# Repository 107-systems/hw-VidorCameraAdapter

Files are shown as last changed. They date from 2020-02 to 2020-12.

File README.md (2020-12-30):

VidorCameraAdapter
==================

<p align="center">
  
</p>

Adapter to connect a OV2640 camera module to the Mini PCIe connector of the Arduino MKR Vidor 4000.

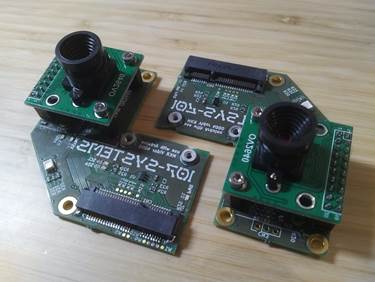
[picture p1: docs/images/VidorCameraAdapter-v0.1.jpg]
VidorCameraAdapter v0.1


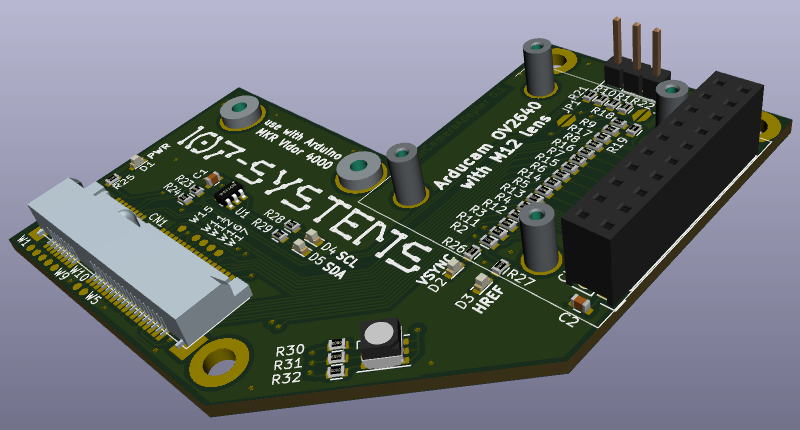
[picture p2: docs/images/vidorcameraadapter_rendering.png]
vidorcameraadapter rendering


## Pinout

This adapter uses only the pins of the Mini PCIe connector of the Arduino MKR Vidor (CN1).

| Pin Number  | Pin Name | Signal | Description |
|:---:|:---:|:---:| --- |
|  1 | WM.WM_PIO2 PEX_PIN1  | n.c. | Connected to the WIFI NINA module on Vidor |
|  3 | WM.WM_PIO3 PEX_PIN3  | n.c. | Connected to the WIFI NINA module on Vidor |
|  5 | WM.WM_PIO4 PEX_PIN5  | n.c. | Connected to the WIFI NINA module on Vidor |
|  6 | PEX_PIN6 | LED_G  | RGB status LED (green) |
|  7 | WM.WM_PIO34 PEX_PIN7 | n.c. | Connected to the WIFI NINA module on Vidor |
|  8 | PEX_PIN8 | LED_R  | RGB status LED (red) |
| 10 | PEX_PIN10 | SDA_V  | I2C to configure OV2640 module |
| 11 | PEX_PIN11 | n.c. | Reserved for future use |
| 12 | PEX_PIN12 | SCL_V  | I2C to configure OV2640 module |
| 13 | PEX_PIN13 | DOUT6  | Data from OV2640 module |
| 14 | PEX_PIN14 | RST | reset for OV2640 module |
| 16 | PEX_PIN16 | PWDN | Power down for OV2640 module |
| 17 | WM.WM_PIO24 | n.c. | Connected to the WIFI NINA module on Vidor |
| 19 | WM.WM_PIO25 | n.c. | Connected to the WIFI NINA module on Vidor |
| 20 | PEX_PIN20 | VSYNC  | Sync from OV2640 module |
| 22 | PEX_RST | n.c. | Pull up resistor on Vidor |
| 23 | PEX_PIN23 | PCLK | Pixel clock from OV2640 module |
| 25 | PEX_PIN25 | DOUT4  | Data from OV2640 module |
| 28 | PEX_PIN28 | HREF | Sync from OV2640 module |
| 30 | PEX_PIN30 | n.c. | Pull up resistor on Vidor |
| 31 | PEX_PIN31 | DOUT5  | Data from OV2640 module |
| 32 | PEX_PIN32 | n.c. | Pull up resistor on Vidor |
| 33 | PEX_PIN33 | DOUT7  | Data from OV2640 module |
| 42 | PEX_PIN42 | DOUT0  | Data from OV2640 module |
| 44 | PEX_PIN44 | DOUT1  | Data from OV2640 module |
| 45 | PEX_PIN45 | LED_B  | RGB status LED (blue) |
| 46 | PEX_PIN46 | DOUT2  | Data from OV2640 module |
| 47 | PEX_PIN47 | XCLK | Clock for OV2640 module |
| 48 | PEX_PIN48 | DOUT3  | Data from OV2640 module |
| 49 | PEX_PIN49 | DOUT8  | Data from OV2640 module |
| 51 | PEX_PIN51 | DOUT9  | Data from OV2640 module |

All GND pins are connected to the GND plane and all +3V3 pins are conntected to the +3V3-rail.

## PCB

### Top

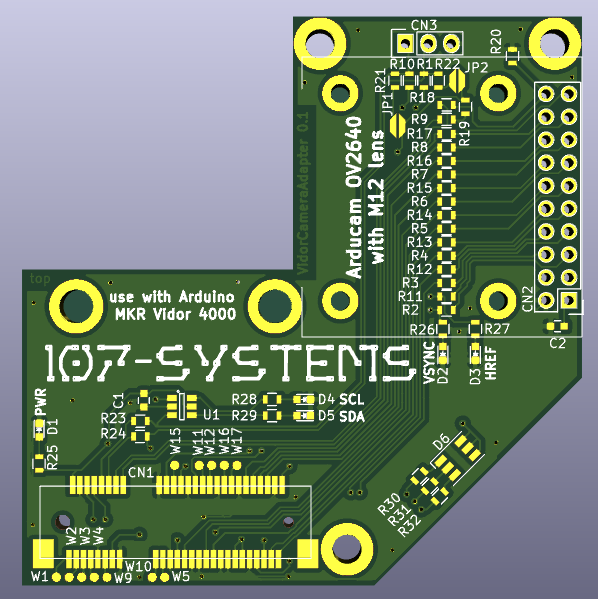
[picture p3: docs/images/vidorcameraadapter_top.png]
vidorcameraadapter PCB top


### Bot

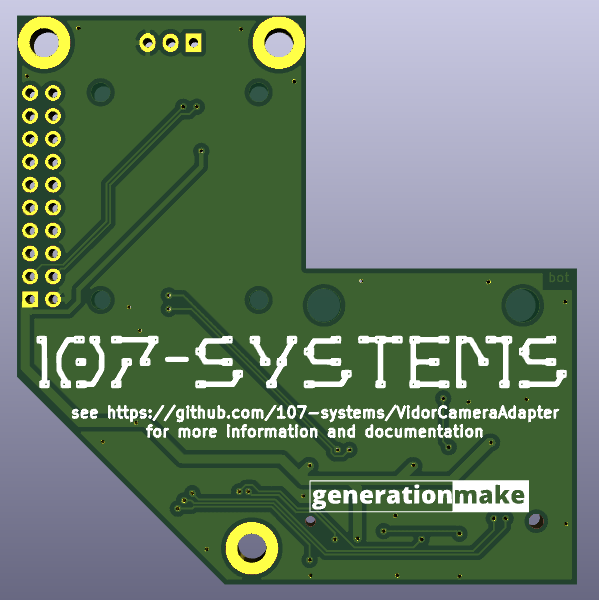
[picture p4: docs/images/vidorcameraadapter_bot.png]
vidorcameraadapter PCB bot


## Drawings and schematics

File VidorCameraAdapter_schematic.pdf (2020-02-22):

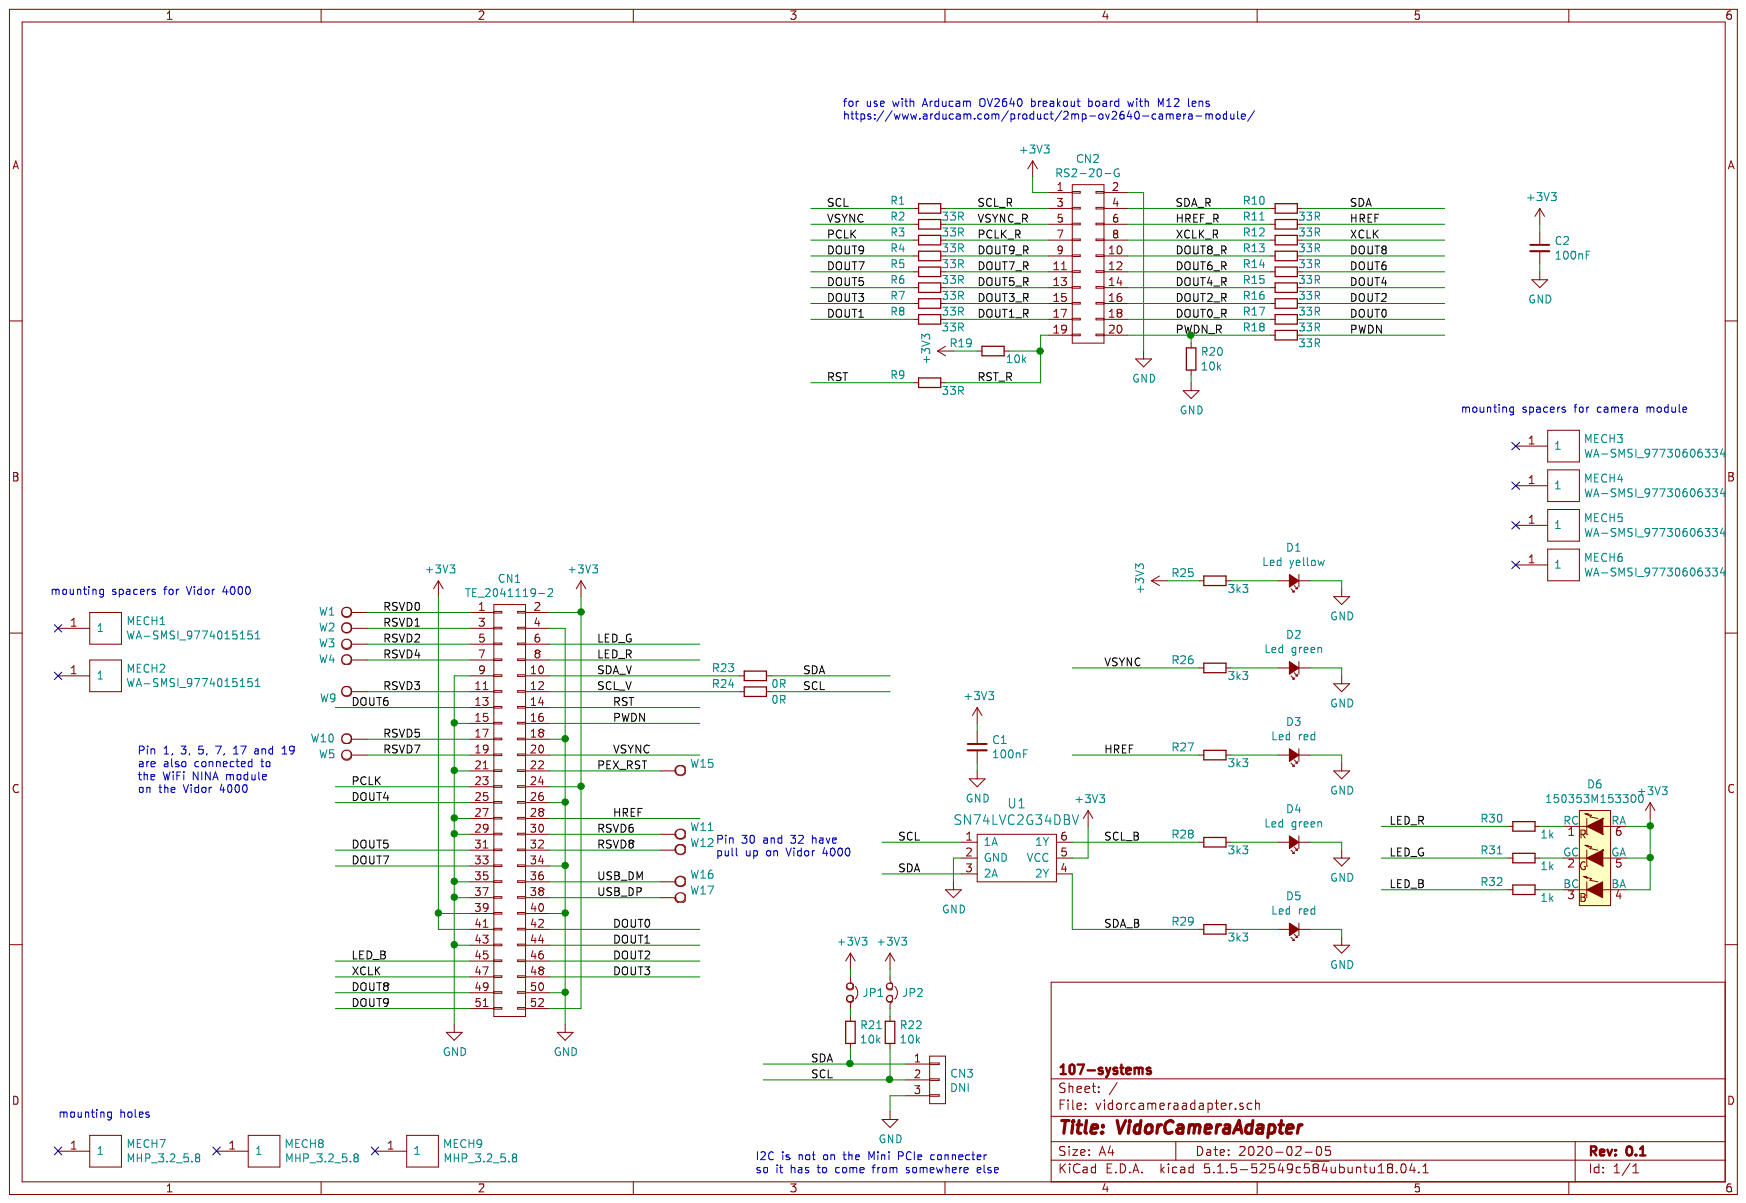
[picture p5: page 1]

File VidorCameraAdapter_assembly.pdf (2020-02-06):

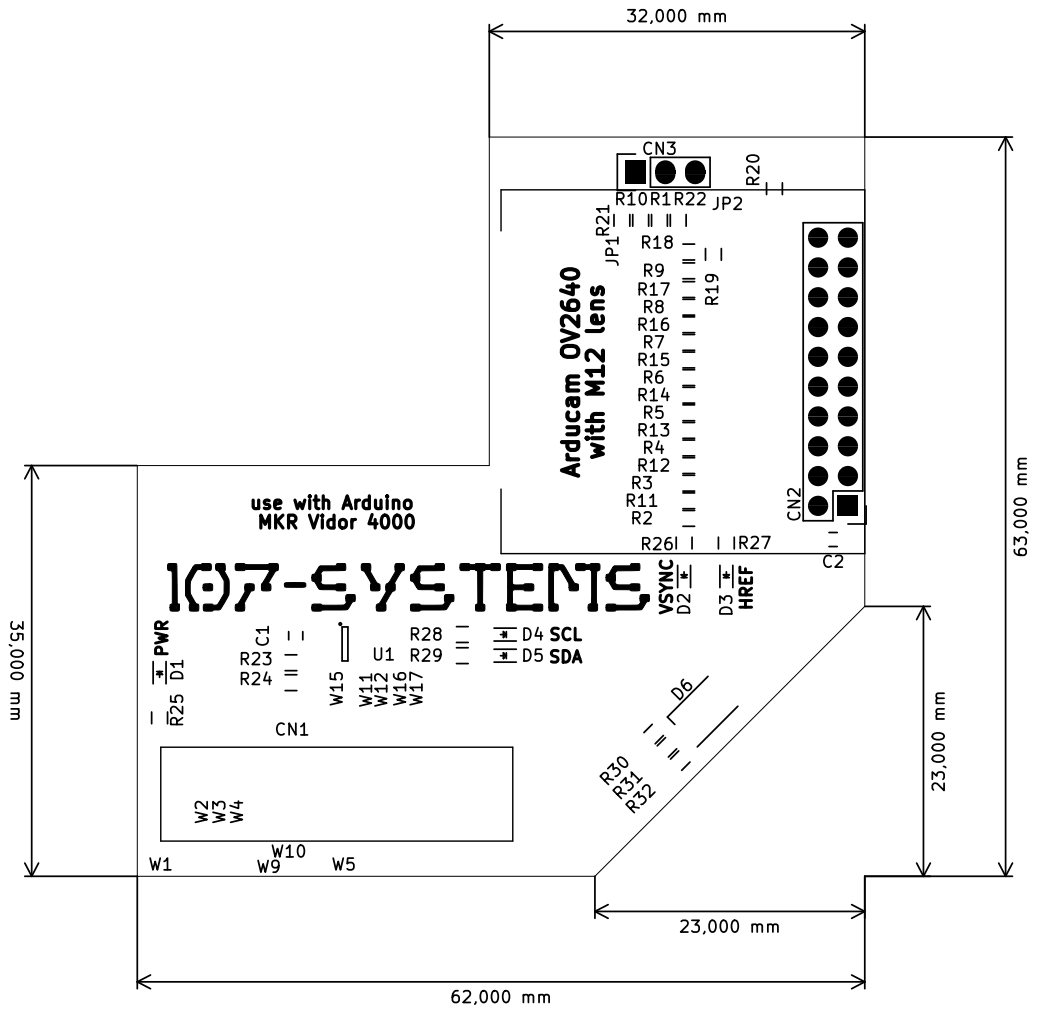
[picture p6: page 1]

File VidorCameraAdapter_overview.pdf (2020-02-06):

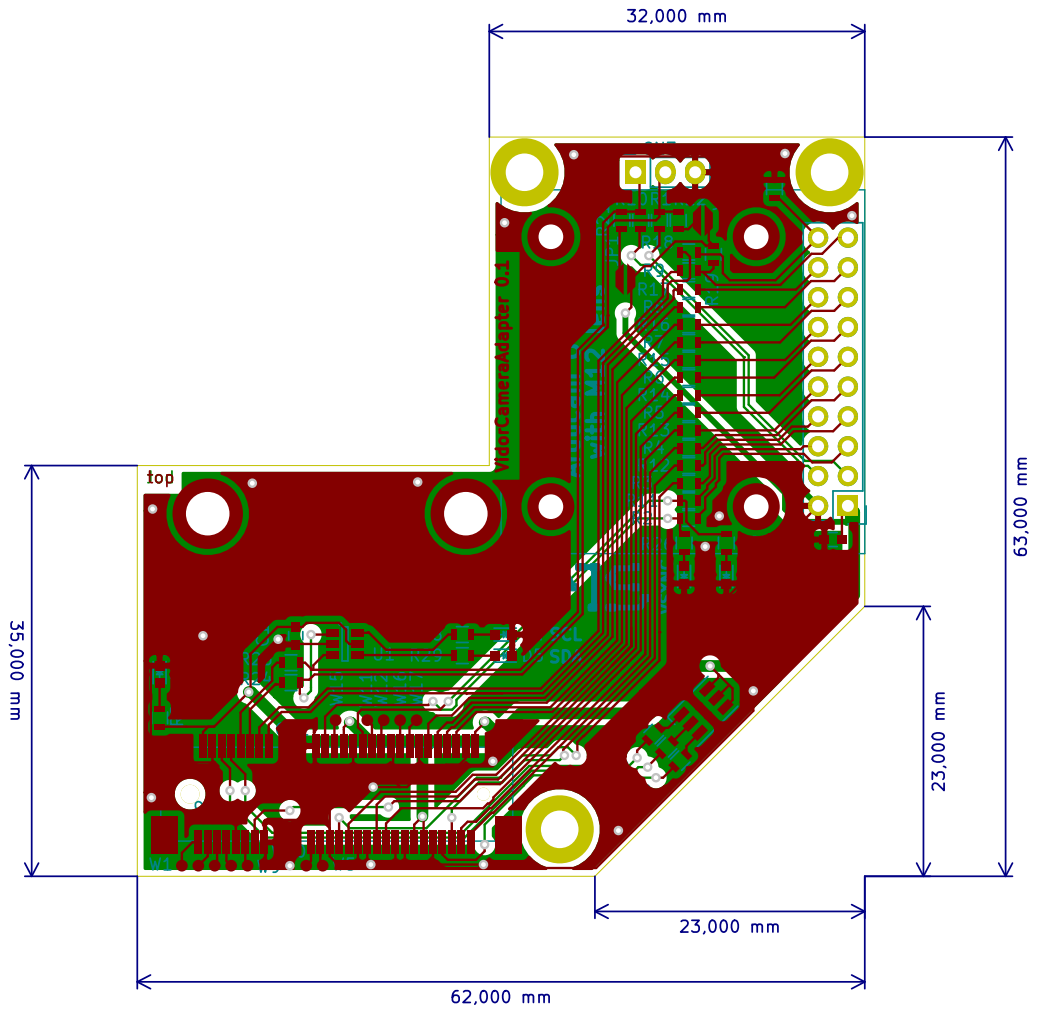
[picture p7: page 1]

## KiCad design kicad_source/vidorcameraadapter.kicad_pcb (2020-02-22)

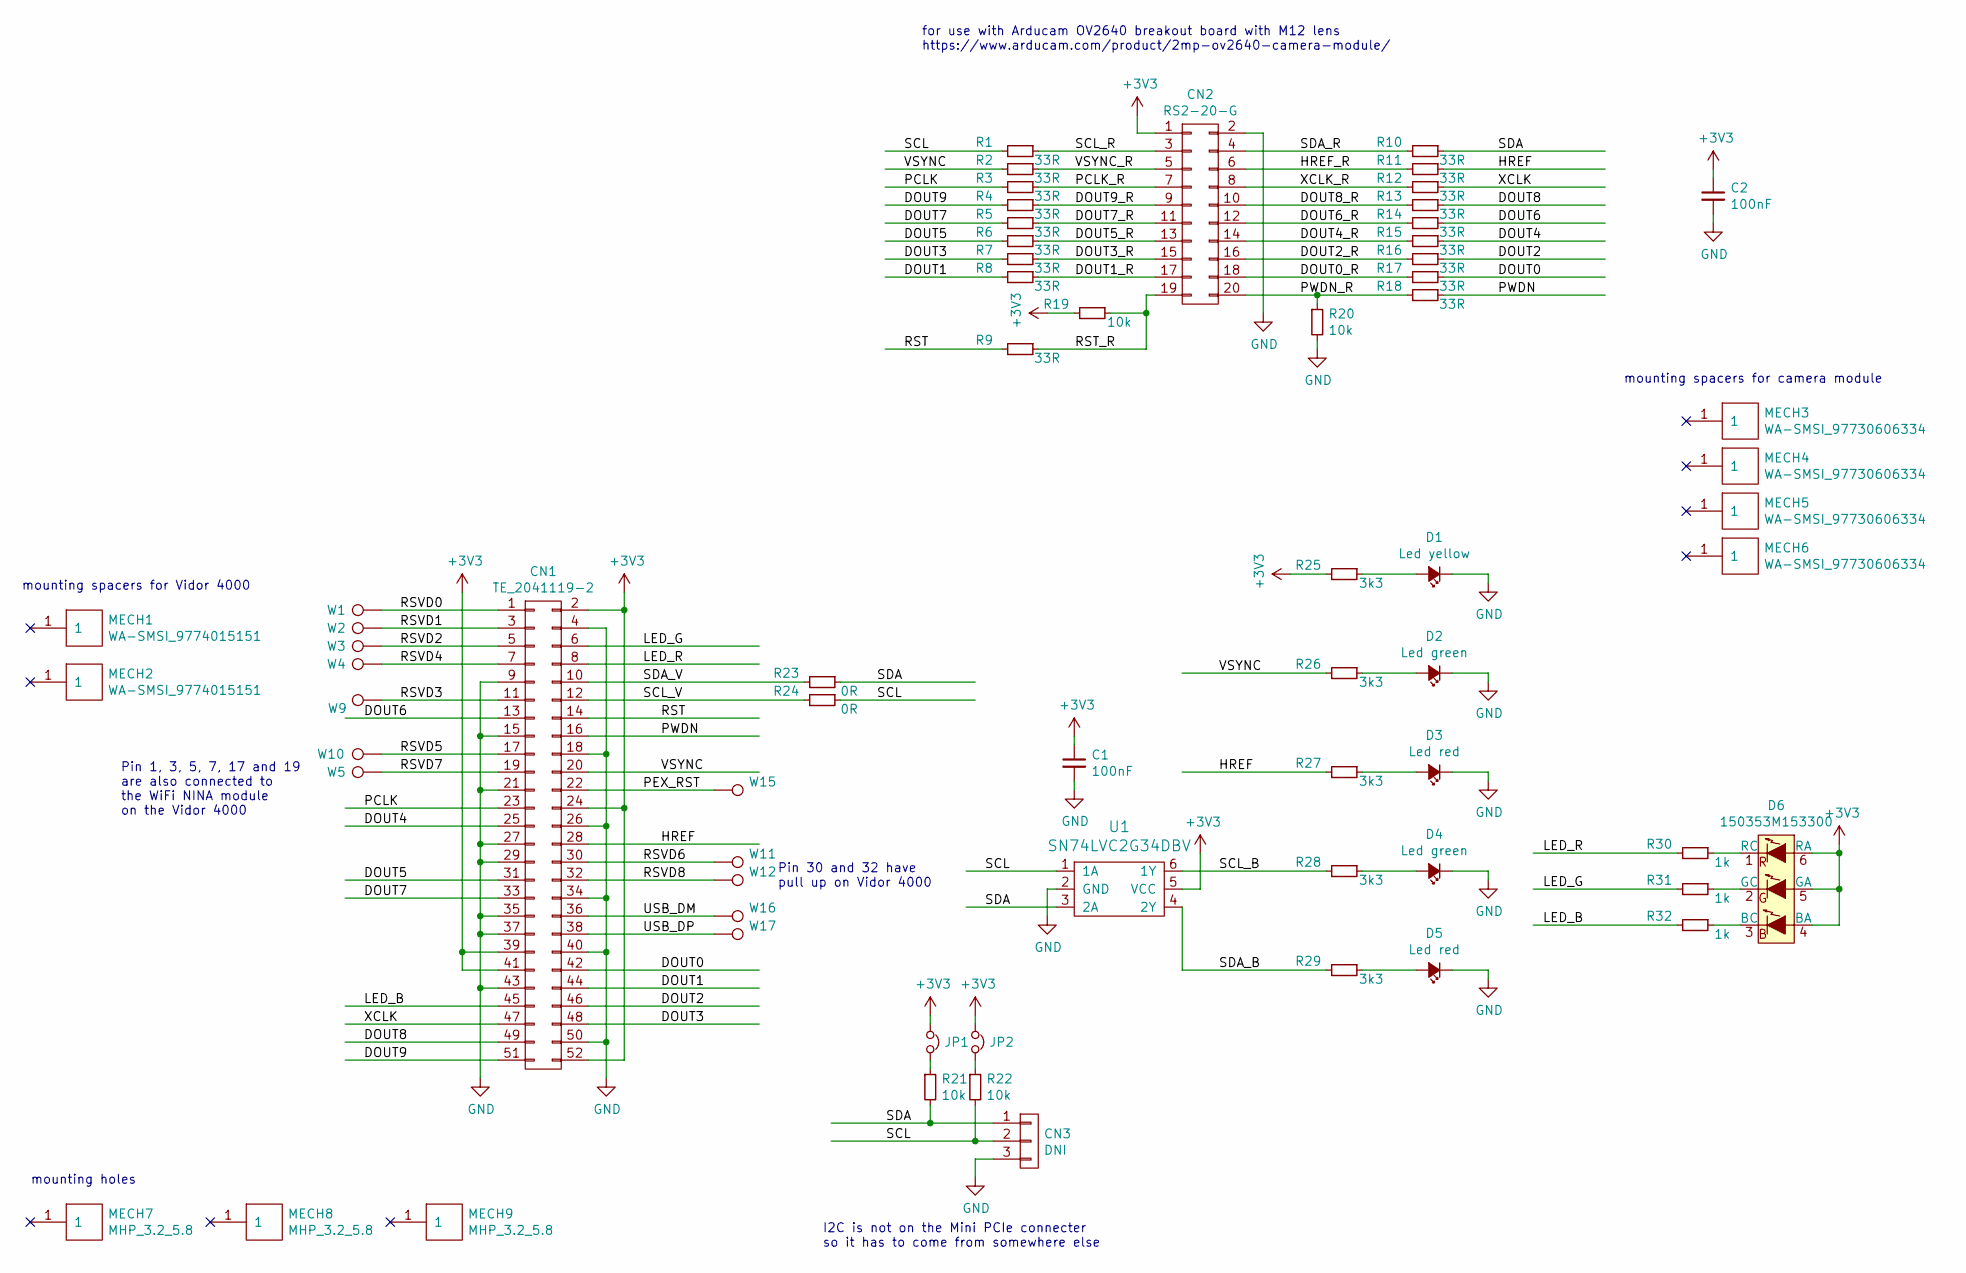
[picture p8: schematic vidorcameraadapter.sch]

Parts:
C1, C2: 100nF; C_0603
CN1: TE_2041119-2; MPCIe_4mm
CN2: RS2-20-G; WR-PHD_61302021821
CN3: DNI; Pin_Header_Straight_1x03
D1: Led yellow; LED_0603
D2, D4: Led green; LED_0603
D3, D5: Led red; LED_0603
D6: 150353M153300; LED_RGB_PLLC-6
JP1, JP2: Jumper_NC_Small; SolderJumper_2mm
MECH1, MECH2: WA-SMSI_9774015151
MECH3, MECH4, MECH5, MECH6: WA-SMSI_97730606334
MECH7, MECH8, MECH9: MHP_3.2_5.8
R1, R2, R3, R4, R5, R6, R7, R8, R9, R10, R11, R12, R13, R14, R15, R16, R17, R18: 33R; R_0603
R19, R20, R21, R22: 10k; R_0603
R23, R24: 0R; R_0603
R25, R26, R27, R28, R29: 3k3; R_0603
R30, R31, R32: 1k; R_0603
U1: SN74LVC2G34DBV; SOT-23-6
W1, W2, W3, W4, W5, W9, W10, W11, W12, W15, W16, W17: TEST_1P; SolderWirePad_single_1mmSMD

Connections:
+3V3: C1.1, C2.1, CN1.2, CN1.24, CN1.39, CN1.41, CN1.52, CN2.1, D6.4 (BA), D6.5 (GA), D6.6 (RA), JP1.1, JP2.1, R19.2, R25.2, U1.5 (VCC)
/DOUT0: CN1.42, R17.1
/DOUT0_R: CN2.18, R17.2
/DOUT1: CN1.44, R8.2
/DOUT1_R: CN2.17, R8.1
/DOUT2: CN1.46, R16.1
/DOUT2_R: CN2.16, R16.2
/DOUT3: CN1.48, R7.2
/DOUT3_R: CN2.15, R7.1
/DOUT4: CN1.25, R15.1
/DOUT4_R: CN2.14, R15.2
/DOUT5: CN1.31, R6.2
/DOUT5_R: CN2.13, R6.1
/DOUT6: CN1.13, R14.1
/DOUT6_R: CN2.12, R14.2
/DOUT7: CN1.33, R5.2
/DOUT7_R: CN2.11, R5.1
/DOUT8: CN1.49, R13.1
/DOUT8_R: CN2.10, R13.2
/DOUT9: CN1.51, R4.2
/DOUT9_R: CN2.9, R4.1
/HREF: CN1.28, R11.1, R27.2
/HREF_R: CN2.6, R11.2
/LED_B: CN1.45, R32.2
/LED_G: CN1.6, R31.2
/LED_R: CN1.8, R30.2
/PCLK: CN1.23, R3.2
/PCLK_R: CN2.7, R3.1
/PEX_RST: CN1.22, W15.1
/PWDN: CN1.16, R18.1
/PWDN_R: CN2.20, R18.2, R20.1
/RST: CN1.14, R9.2
/RST_R: CN2.19, R9.1, R19.1
/RSVD0: CN1.1, W1.1
/RSVD1: CN1.3, W2.1
/RSVD2: CN1.5, W3.1
/RSVD3: CN1.11, W9.1
/RSVD4: CN1.7, W4.1
/RSVD5: CN1.17, W10.1
/RSVD6: CN1.30, W11.1
/RSVD7: CN1.19, W5.1
/RSVD8: CN1.32, W12.1
/SCL: CN3.2, R1.2, R22.2, R24.1, U1.1 (1A)
/SCL_B: R28.2, U1.6 (1Y)
/SCL_R: CN2.3, R1.1
/SCL_V: CN1.12, R24.2
/SDA: CN3.1, R10.1, R21.2, R23.1, U1.3 (2A)
/SDA_B: R29.2, U1.4 (2Y)
/SDA_R: CN2.4, R10.2
/SDA_V: CN1.10, R23.2
/USB_DM: CN1.36, W16.1
/USB_DP: CN1.38, W17.1
/VSYNC: CN1.20, R2.2, R26.2
/VSYNC_R: CN2.5, R2.1
/XCLK: CN1.47, R12.1
/XCLK_R: CN2.8, R12.2
GND: C1.2, C2.2, CN1.4, CN1.9, CN1.15, CN1.18, CN1.21, CN1.26, CN1.27, CN1.29, CN1.34, CN1.35, CN1.37, CN1.40, CN1.43, CN1.50, CN2.2, CN3.3, D1.1 (K), D2.1 (K), D3.1 (K), D4.1 (K), D5.1 (K), R20.2, U1.2 (GND)
unnamed: D1.2 (A), R25.1
unnamed: D2.2 (A), R26.1
unnamed: D3.2 (A), R27.1
unnamed: D4.2 (A), R28.1
unnamed: D5.2 (A), R29.1
unnamed: D6.1 (RC), R30.1
unnamed: D6.2 (GC), R31.1
unnamed: D6.3 (BC), R32.1
unnamed: JP1.2, R21.1
unnamed: JP2.2, R22.1

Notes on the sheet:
Pin 30 and 32 have pull up on Vidor 4000
mounting spacers for Vidor 4000
mounting spacers for camera module
I2C is not on the Mini PCIe connecter so it has to come from somewhere else
for use with Arducam OV2640 breakout board with M12 lens https://www.arducam.com/product/2mp-ov2640-camera-module/
mounting holes
Pin 1, 3, 5, 7, 17 and 19 are also connected to the WiFi NINA module on the Vidor 4000

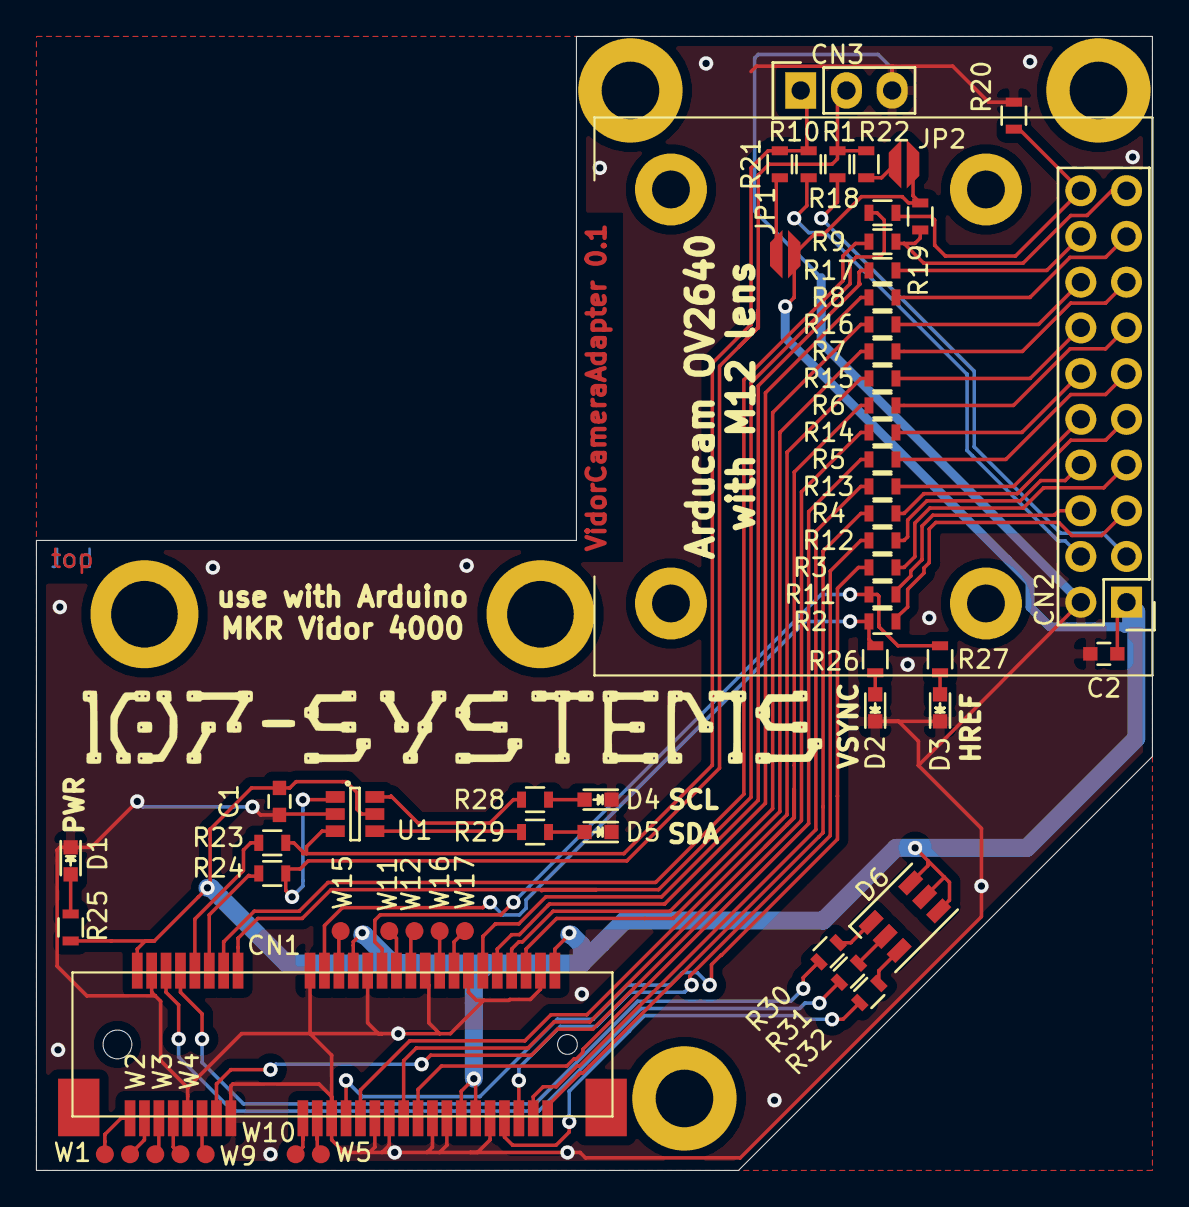
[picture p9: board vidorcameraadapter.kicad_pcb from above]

Board: 2 copper layers, 62.0 x 63.0 mm, 67 parts (0 on the bottom side), 67 nets.

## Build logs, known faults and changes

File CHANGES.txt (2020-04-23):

VidorCameraAdaptder - connect a OV2640 parallel camera to the Mini PCIe connector of the Arduino MKR Vidor 4000
see full documentation at https://github.com/107-systems/VidorCameraAdapter

changes

version 0.1 - 2020-02-05
* initial release

version 0.1.1 - 2020-02-22
* changed resistors for leds from 1k to 3k3

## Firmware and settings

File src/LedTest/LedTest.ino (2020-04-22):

// test program for all the LEDs on the VidorCameraAdapter
#include "VidorPeripherals.h"
const static int START_DELAY = 500;
const static int FPGA_LED_RED_PIN = 2;
const static int FPGA_LED_GREEN_PIN = 1;
const static int FPGA_LED_BLUE_PIN = 13;
const static int FPGA_I2C_SDA_PIN = 3;
const static int FPGA_I2C_SCL_PIN = 4;
const static int FPGA_VSYNC_PIN = 7;
const static int FPGA_HREF_PIN = 8;

void setup() {
  Serial.begin(115200);
  for(unsigned long const start = millis(); !Serial && (millis() - start) < 5000; ) {}  // wait for five seconds if Serial starts and then move on
  // Let's start by initializing the FPGA
  if (!FPGA.begin()) {
    Serial.println("Initialization failed!");
    while (1) {}
  }

  // Let's discover which version we are running
  int version = FPGA.version();
  Serial.print("Vidor bitstream version: ");
  Serial.println(version, HEX);
  pinMode(LED_BUILTIN, OUTPUT);

  // Let's also ask which IPs are included in this bitstream
  FPGA.printConfig();

  // Set FGPA gpios
  FPGA.pinMode(FPGA_I2C_SDA_PIN, OUTPUT);
  FPGA.pinMode(FPGA_I2C_SCL_PIN, OUTPUT);
  FPGA.pinMode(FPGA_VSYNC_PIN, OUTPUT);
  FPGA.pinMode(FPGA_HREF_PIN, OUTPUT);
  FPGA.pinMode(FPGA_LED_RED_PIN, OUTPUT);
  FPGA.pinMode(FPGA_LED_GREEN_PIN, OUTPUT);
  FPGA.pinMode(FPGA_LED_BLUE_PIN, OUTPUT);
  FPGA.digitalWrite(FPGA_I2C_SDA_PIN, LOW);
  FPGA.digitalWrite(FPGA_I2C_SCL_PIN, LOW);
  FPGA.digitalWrite(FPGA_VSYNC_PIN, LOW);
  FPGA.digitalWrite(FPGA_HREF_PIN, LOW);
  FPGA.digitalWrite(FPGA_LED_RED_PIN, HIGH);
  FPGA.digitalWrite(FPGA_LED_GREEN_PIN, HIGH);
  FPGA.digitalWrite(FPGA_LED_BLUE_PIN, HIGH);
}

void setRGBLed (bool red, bool green, bool blue) {
  if(red==true) FPGA.digitalWrite(FPGA_LED_RED_PIN, LOW);
  else FPGA.digitalWrite(FPGA_LED_RED_PIN, HIGH);
  if(green==true) FPGA.digitalWrite(FPGA_LED_GREEN_PIN, LOW);
  else FPGA.digitalWrite(FPGA_LED_GREEN_PIN, HIGH);
  if(blue==true) FPGA.digitalWrite(FPGA_LED_BLUE_PIN, LOW);
  else FPGA.digitalWrite(FPGA_LED_BLUE_PIN, HIGH);
}

void loop() {
  int i=0;
  // put your main code here, to run repeatedly:
  FPGA.digitalWrite(FPGA_I2C_SDA_PIN, HIGH);  // activate LED on I2CSDA
  delay(START_DELAY);
  FPGA.digitalWrite(FPGA_I2C_SDA_PIN, LOW);
  FPGA.digitalWrite(FPGA_I2C_SCL_PIN, HIGH);  // activate LED on I2CSCL
  delay(START_DELAY);
  FPGA.digitalWrite(FPGA_I2C_SCL_PIN, LOW);
  FPGA.digitalWrite(FPGA_VSYNC_PIN, HIGH);  // activate LED on VSYNC
  delay(START_DELAY);
  FPGA.digitalWrite(FPGA_VSYNC_PIN, LOW);
  FPGA.digitalWrite(FPGA_HREF_PIN, HIGH);  // activate LED on HSYNC
  delay(START_DELAY);
  FPGA.digitalWrite(FPGA_HREF_PIN, LOW);

  // now activate all LEDs of the RGB LED one after another
  setRGBLed(1,0,0);
  delay(START_DELAY);
  setRGBLed(0,1,0);
  delay(START_DELAY);
  setRGBLed(0,0,1);
  delay(START_DELAY);
  setRGBLed(1,1,1);
  delay(START_DELAY);
  setRGBLed(0,0,0);
  delay(START_DELAY);

  for(i=0;i<3;i++)
  {
    FPGA.digitalWrite(FPGA_I2C_SDA_PIN, HIGH);  // activate all LEDs
    FPGA.digitalWrite(FPGA_I2C_SCL_PIN, HIGH);
    FPGA.digitalWrite(FPGA_VSYNC_PIN, HIGH);
    FPGA.digitalWrite(FPGA_HREF_PIN, HIGH);
    setRGBLed(1,1,1);
    delay(START_DELAY);
    FPGA.digitalWrite(FPGA_I2C_SDA_PIN, LOW);  // deactivate all LEDs
    FPGA.digitalWrite(FPGA_I2C_SCL_PIN, LOW);
    FPGA.digitalWrite(FPGA_VSYNC_PIN, LOW);
    FPGA.digitalWrite(FPGA_HREF_PIN, LOW);
    setRGBLed(0,0,0);
    delay(START_DELAY);
  }
}

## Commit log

2020-01-28 added kicad source
    [vidorcameraadapter.kicad_pcb, vidorcameraadapter.sch]
2020-01-28 added schematic pdf
2020-01-28 corrected spacers, added resistors, made layout
    [vidorcameraadapter.kicad_pcb, vidorcameraadapter.sch]
2020-01-28 added 3d models, added mounting holes
    [vidorcameraadapter.kicad_pcb, vidorcameraadapter.sch]
2020-01-28 added testpoints for all unused pins
    [vidorcameraadapter.kicad_pcb, vidorcameraadapter.sch]
2020-01-29 updated layout, made edge smoother, generated pdf schematic and images
    [vidorcameraadapter.kicad_pcb, vidorcameraadapter.sch]
2020-01-30 added pull up for I2C and RST, added pull down for pwdn
    [vidorcameraadapter.sch]
2020-01-30 connected I2C to Vidor 4000, added LEDs
    [vidorcameraadapter.sch]
2020-01-31 added RGB led
    [vidorcameraadapter.kicad_pcb, vidorcameraadapter.sch]
2020-01-31 placed all new parts in layout
    [vidorcameraadapter.kicad_pcb, vidorcameraadapter.sch]
2020-01-31 moved camera connector to unblock HDMI connector on Vidor 4000, connected all traces again
    [vidorcameraadapter.kicad_pcb]
2020-02-01 added logo and description on silkscreen
    [vidorcameraadapter.kicad_pcb, vidorcameraadapter.sch]
2020-02-03 added jumper for I2C pullup, added buffer ic for I2C leds, made mounting holes as parts, made DRC, updated images
    [vidorcameraadapter.kicad_pcb, vidorcameraadapter.sch]
2020-02-05 moved pins on the Vidor connector to free NINA pins and pins with pull up, exchanged PCLK and XCLK, added pdfs and generated images
    [vidorcameraadapter.kicad_pcb, vidorcameraadapter.sch]
2020-02-05 changed pinning to fit to https://github.com/107-systems/viper-vidor-fpga
    [vidorcameraadapter.kicad_pcb, vidorcameraadapter.sch]
2020-02-22 changed resistors for led from 1k to 3k3, added changes file
    [vidorcameraadapter.sch]
2020-02-22 added step file of pcb
    [vidorcameraadapter.kicad_pcb]
2020-02-23 updated symbold for vidor mpcie connector in schematic
    [vidorcameraadapter.sch]
2020-02-23 made pcb smaller to avoid collision with MKR connector
    [vidorcameraadapter.kicad_pcb]
2020-02-24 Centering contents of pin-out table
2020-03-16 Adding picture of populated PCBs with camera module
2020-04-19 added test software to toggle all LEDs on the board
2020-04-19 restored design files from master
    [vidorcameraadapter.kicad_pcb, vidorcameraadapter.sch]
2020-04-21 added timeout for Serial init, replaced defines by consts
    [LedTest.ino]
2020-04-22 Check for commonly misspelled words during CI build
    Use codespell to check the repository's files for typos.
    In the event of false positives, words to ignore may be added to etc/codespell-ignore-words-list.txt. Although the typo check is case-insensitive, the ignore words list is case-sensitive, and the mis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
